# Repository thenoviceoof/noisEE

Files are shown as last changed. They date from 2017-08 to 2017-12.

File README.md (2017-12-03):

noiseEE
================================================================================
Code to find a set of easily derivable software filters to produce
different flavors of noise and intermediate stages, and a hardware
realization.

If you want a full explanation of the project, see notes [part
1](http://thenoviceoof.com/blog/projects/noisee-part-1-software/) and
[part
2](http://thenoviceoof.com/blog/projects/noisee-part-2-hardware/).

**NOTE**: the hardware rendition does not work, and will be expensive
in time to correct. This project is abandoned.

filter/
--------------------------------------------------------------------------------
Contains scripts to help find and visualize the filter parameters.

- `exploration_parameters.py`: exploratory work, lots of commented out
  code. Generates graphics to investigate whether simple linear
  parameter interpolation would work.

- `ideal_parameters.py`: hill climb the gain parameters of a joint
  filter made of 3 low pass filters to create linear slope
  approximations, using ideal filter transfer functions. Generates
  `gains.csv`.

- `linear_approximation.R`: takes in `gains.csv` (currently a more
  specific name; you'll need to edit the file) and uses R's segmented
  library to get a piecewise linear approximation. Generates
  `linear_parameters.csv`.

- `generate_hardware_parameter.py`: takes in `linear_parameters.csv`,
  and prints out 16-bit fixed-point integer gain parameters for use in
  `noisEE.c`.

There are also scripts generating multimedia:

- `generate_audio.py`: given the piecemeal results in
  `linear_parameters.csv`, generate a WAV file sweeping from white to
  red noise.

- `visualized_spectrum.py`: running this will generate figures used in
  [part 1 of the project
  notes](http://thenoviceoof.com/blog/projects/noisee-part-1-software/).

- `visualized_animated_spectrum.py`: running this will generate
  animation frames used for the spectrum animation in [part 1 of the
  project
  notes](http://thenoviceoof.com/blog/projects/noisee-part-1-software/).

hardware/
--------------------------------------------------------------------------------
Contains the hardware design files.

- `noisEE-project*`: KiCad design files. Start with the `.pro` project file.

- `noisEE-components*`: contains the OPA227 symbol and MEE1SC footprint
  for KiCad.

- `case__1_5mm.svg/case__3_0mm.svg`: the SVG design files fit into
  Ponoko's P1 template, meant for their respective wood thicknesses.

- `case_*.svg`: these SVGs are intermediate design files, mostly
  correcting for laser kerf.

avr/
--------------------------------------------------------------------------------
Contains files for programming the AVR.

- `Makefile`: just run `make` to build and upload, if you have `avr-gcc`
  and `avrdude` on your path, and are using the ISP MKII. You'll need
  to edit this file if you're using something else.

- `noisEE.c`: currently in a bad state, checkpointed in the middle of
  testing how each filter affects the final response. If you want to
  continue work, you'll need to remove the test loop and uncomment the
  real runtime loop.

(other)
--------------------------------------------------------------------------------

- `test_binary_search_loop.py`: a quick script to make sure that a
  binary search on the calculated filter values will terminate.

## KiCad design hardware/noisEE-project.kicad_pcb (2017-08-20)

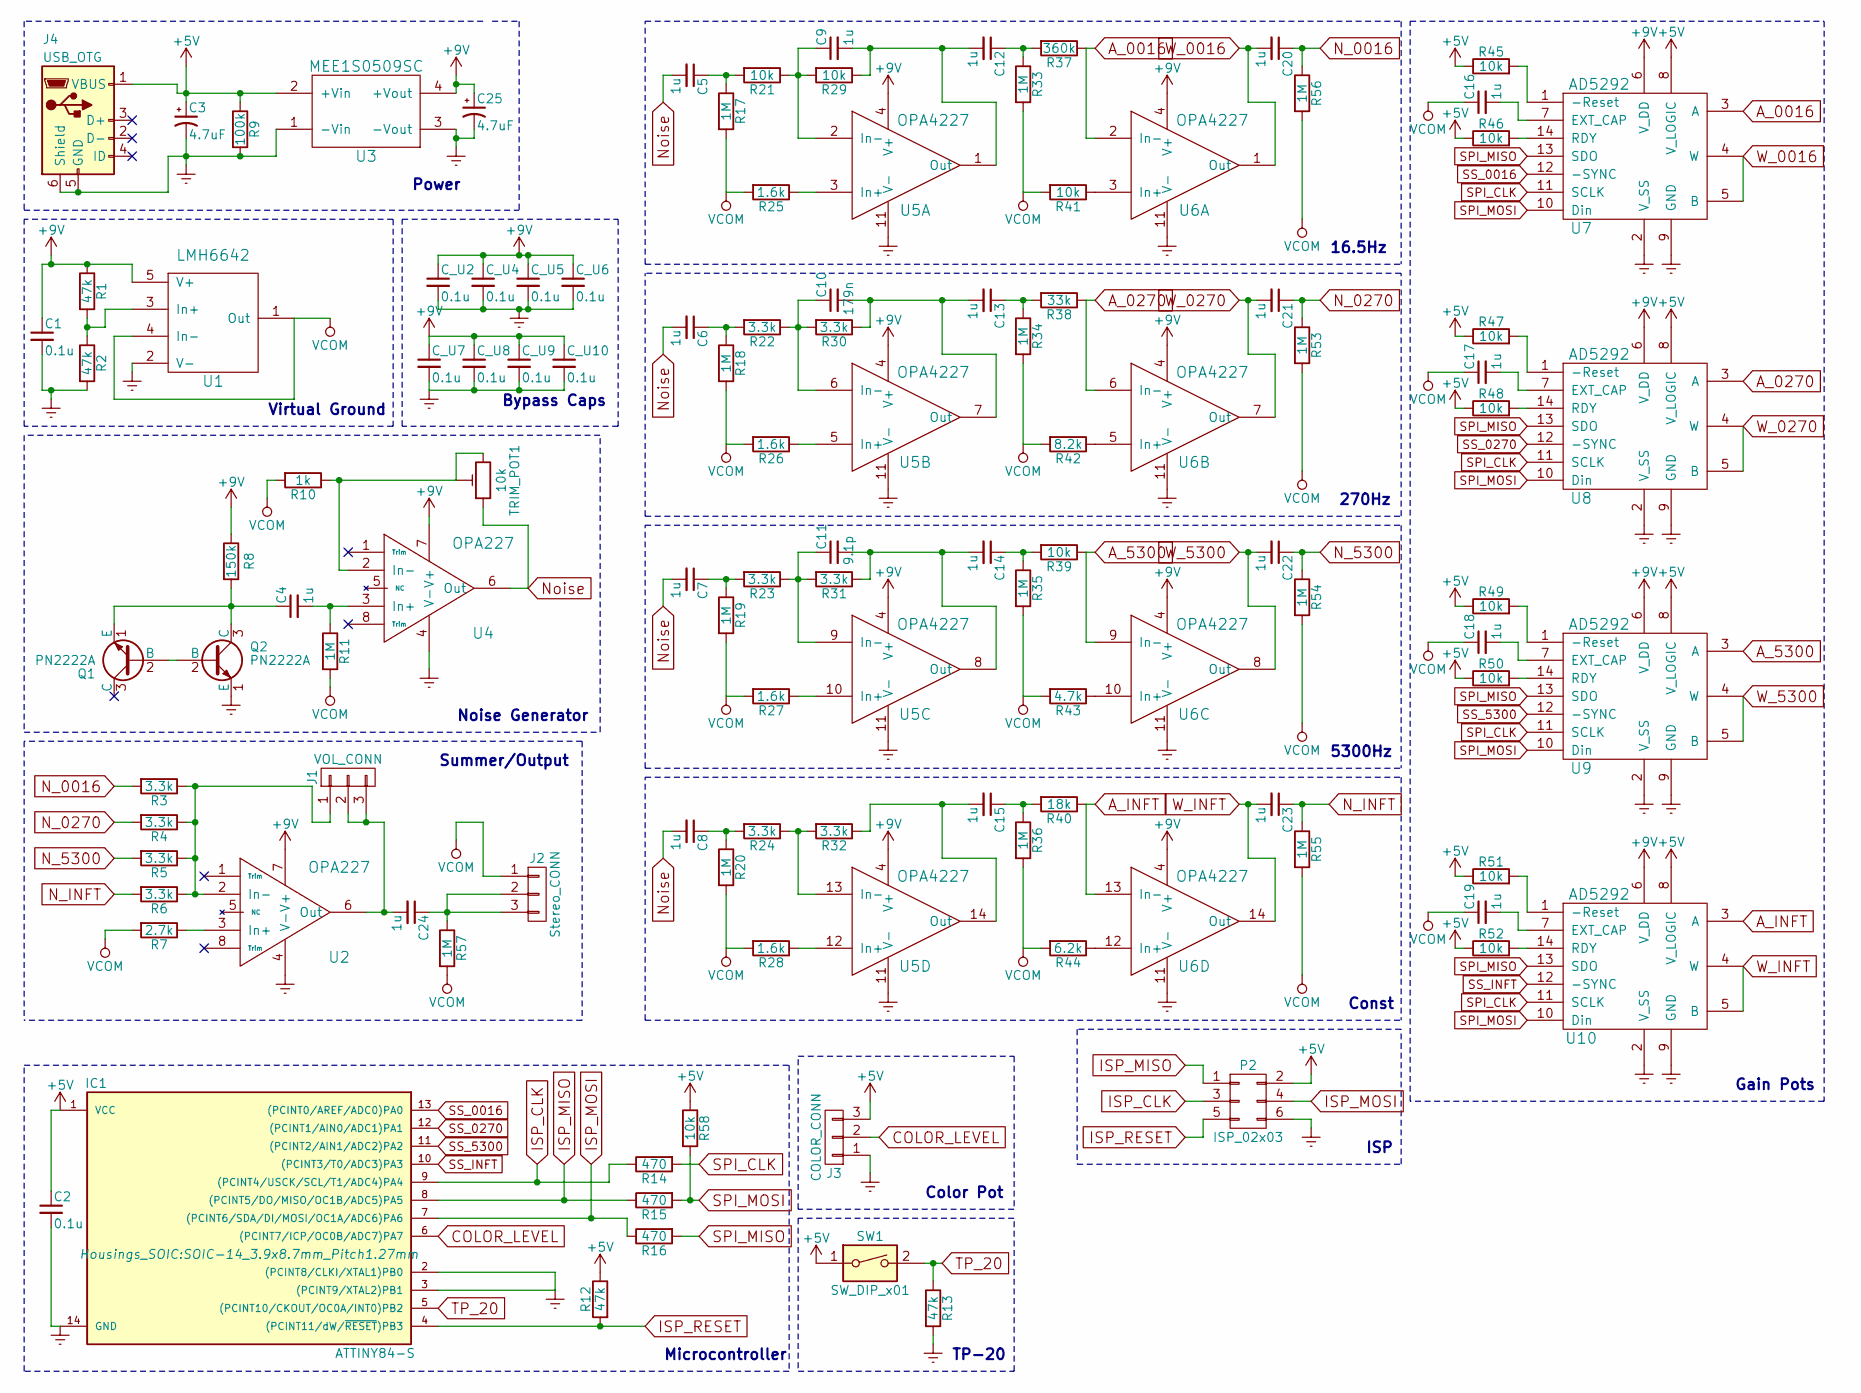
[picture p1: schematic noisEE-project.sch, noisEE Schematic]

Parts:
C1, C2: 0.1u; C_0805
C3, C25: 4.7uF; CP_Radial_D8.0mm_P3.50mm
C4, C5, C6, C7, C8, C9, C12, C13, C14, C15, C16, C17, C18, C19, C20, C21, C22, C23, C24: 1u; C_0805
C10: 179n; C_0805
C11: 9.1p; C_0805
C_U2, C_U4, C_U5, C_U6, C_U7, C_U8, C_U9, C_U10: 0.1u; C_0805
IC1: ATTINY84-S; SOIC-14_3.9x8.7mm_Pitch1.27mm
J1: VOL_CONN; Pin_Header_Straight_1x03_Pitch2.54mm
J2: Stereo_CONN; Pin_Header_Straight_1x03_Pitch2.54mm
J3: COLOR_CONN; Pin_Header_Straight_1x03_Pitch2.54mm
J4: USB_OTG; USB_Micro-B_10103594-0001LF
P2: ISP_02x03; Pin_Header_Straight_2x03_Pitch2.54mm
Q1, Q2: PN2222A; TO-92_Inline_Wide
R1, R2, R12, R13: 47k; R_0805
R3, R4, R5, R6, R22, R23, R24, R30, R31, R32: 3.3k; R_0805
R7: 2.7k; R_0805
R8: 150k; R_0805
R9: 100k; R_0805
R10: 1k; R_0805
R11, R17, R18, R19, R20, R33, R34, R35, R36, R53, R54, R55, R56, R57: 1M; R_0805
R14, R15, R16: 470; R_0805
R21, R29, R39, R41, R45, R46, R47, R48, R49, R50, R51, R52, R58: 10k; R_0805
R25, R26, R27, R28: 1.6k; R_0805
R37: 360k; R_0805
R38: 33k; R_0805
R40: 18k; R_0805
R42: 8.2k; R_0805
R43: 4.7k; R_0805
R44: 6.2k; R_0805
SW1: SW_DIP_x01; SW_TH_Tactile_Omron_B3F-10xx
TRIM_POT1: 10k; Potentiometer_Trimmer_Bourns_3339P_Horizontal
U1: LMH6642; SOT-23-5
U2, U4: OPA227; SOIC-8_3.9x4.9mm_Pitch1.27mm
U3: MEE1S0509SC; MEE1SC
U5, U6: OPA4227; SOIC-14_3.9x8.7mm_Pitch1.27mm
U7, U8, U9, U10: AD5292; TSSOP-14_4.4x5mm_Pitch0.65mm

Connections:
+5V: C2.1, C3.1, IC1.1 (VCC), J3.3, J4.1 (VBUS), P2.2, R9.1, R12.1, R45.1, R46.1, R47.1, R48.1, R49.1, R50.1, R51.1, R52.1, R58.1, SW1.1, U3.2 (+Vin), U7.8 (V_LOGIC), U8.8 (V_LOGIC), U9.8 (V_LOGIC), U10.8 (V_LOGIC)
+9V: C1.1, C25.1, C_U2.1, C_U4.1, C_U5.1, C_U6.1, C_U7.1, C_U8.1, C_U9.1, C_U10.1, R1.1, R8.1, U1.5 (V+), U2.7 (V+), U3.4 (+Vout), U4.7 (V+), U5.4 (V+), U6.4 (V+), U7.6 (V_DD), U8.6 (V_DD), U9.6 (V_DD), U10.6 (V_DD); also elsewhere on the board
A_0016: R37.1, U6.2 (In-), U7.3 (A)
A_0270: R38.1, U6.6 (In-), U8.3 (A)
A_5300: R39.1, U6.9 (In-), U9.3 (A)
A_INFT: R40.1, U6.13 (In-), U10.3 (A)
COLOR_LEVEL: IC1.6 ((PCINT7/ICP/OC0B/ADC7)PA7), J3.2
Earth: C1.2, C2.2, C3.2, C25.2, C_U2.2, C_U4.2, C_U5.2, C_U6.2, C_U7.2, C_U8.2, C_U9.2, C_U10.2, IC1.2 ((PCINT8/CLKI/XTAL1)PB0), IC1.3 ((PCINT9/XTAL2)PB1), IC1.14 (GND), J3.1, J4.5 (GND), J4.6 (Shield), P2.6, Q2.1 (E), R2.2, R9.2, R13.2, U1.2 (V-), U2.4 (V-), U3.1 (-Vin), U3.3 (-Vout), U4.4 (V-), U5.11 (V-), U6.11 (V-), U7.2 (V_SS), U7.9 (GND), U8.2 (V_SS), U8.9 (GND), U9.2 (V_SS), U9.9 (GND), U10.2 (V_SS), U10.9 (GND); also elsewhere on the board
ISP_CLK: IC1.9 ((PCINT4/USCK/SCL/T1/ADC4)PA4), P2.3, R14.1
ISP_MISO: IC1.8 ((PCINT5/DO/MISO/OC1B/ADC5)PA5), P2.1, R15.1
ISP_MOSI: IC1.7 ((PCINT6/SDA/DI/MOSI/OC1A/ADC6)PA6), P2.4, R16.1
ISP_RESET: IC1.4 ((PCINT11/dW/~RESET~)PB3), P2.5, R12.2
N_0016: C20.1, R3.2, R56.1
N_0270: C21.1, R4.2, R53.1
N_5300: C22.1, R5.2, R54.1
N_INFT: C23.1, R6.2, R55.1
unnamed: C4.1, Q1.1 (E), Q2.3 (C), R8.2
unnamed: C4.2, R11.1, U4.3 (In+)
unnamed: C5.1, R17.1, R21.2
unnamed: C6.1, R18.1, R22.2
unnamed: C7.1, R19.1, R23.2
unnamed: C8.1, R20.1, R24.2
unnamed: C9.1, R21.1, R29.2, U5.2 (In-)
unnamed: C10.1, R22.1, R30.2, U5.6 (In-)
unnamed: C10.2, C13.2, R30.1, U5.7 (Out)
unnamed: C11.1, R23.1, R31.2, U5.9 (In-)
unnamed: C11.2, C14.2, R31.1, U5.8 (Out)
unnamed: C12.1, R33.1, R37.2
unnamed: C9.2, C12.2, R29.1, U5.1 (Out)
unnamed: C13.1, R34.1, R38.2
unnamed: C14.1, R35.1, R39.2
unnamed: C15.1, R36.1, R40.2
unnamed: C15.2, R32.1, U5.14 (Out)
unnamed: C16.2, U7.7 (EXT_CAP)
unnamed: C17.2, U8.7 (EXT_CAP)
unnamed: C18.2, U9.7 (EXT_CAP)
unnamed: C19.2, U10.7 (EXT_CAP)
unnamed: C24.1, J2.2, J2.3, R57.1
unnamed: C24.2, J1.2, J1.3, U2.6 (Out)
unnamed: J1.1, R3.1, R4.1, R5.1, R6.1, U2.2 (In-)
unnamed: Q1.2 (B), Q2.2 (B)
unnamed: R1.2, R2.1, U1.3 (In+)
unnamed: R7.1, U2.3 (In+)
unnamed: R10.1, TRIM_POT1.2, TRIM_POT1.3, U4.2 (In-)
unnamed: R24.1, R32.2, U5.13 (In-)
unnamed: R25.1, U5.3 (In+)
unnamed: R26.1, U5.5 (In+)
unnamed: R27.1, U5.10 (In+)
unnamed: R28.1, U5.12 (In+)
unnamed: R41.1, U6.3 (In+)
unnamed: R42.1, U6.5 (In+)
unnamed: R43.1, U6.10 (In+)
unnamed: R44.1, U6.12 (In+)
unnamed: R45.2, U7.1 (-Reset)
unnamed: R46.2, U7.14 (RDY)
unnamed: R47.2, U8.1 (-Reset)
unnamed: R48.2, U8.14 (RDY)
unnamed: R49.2, U9.1 (-Reset)
unnamed: R50.2, U9.14 (RDY)
unnamed: R51.2, U10.1 (-Reset)
unnamed: R52.2, U10.14 (RDY)
Noise: C5.2, C6.2, C7.2, C8.2, TRIM_POT1.1, U4.6 (Out)
SPI_CLK: R14.2, U7.11 (SCLK), U8.11 (SCLK), U9.11 (SCLK), U10.11 (SCLK)
SPI_MISO: R16.2, U7.13 (SDO), U8.13 (SDO), U9.13 (SDO), U10.13 (SDO)
SPI_MOSI: R15.2, R58.2, U7.10 (Din), U8.10 (Din), U9.10 (Din), U10.10 (Din)
SS_0016: IC1.13 ((PCINT0/AREF/ADC0)PA0), U7.12 (-SYNC)
SS_0270: IC1.12 ((PCINT1/AIN0/ADC1)PA1), U8.12 (-SYNC)
SS_5300: IC1.11 ((PCINT2/AIN1/ADC2)PA2), U9.12 (-SYNC)
SS_INFT: IC1.10 ((PCINT3/T0/ADC3)PA3), U10.12 (-SYNC)
TP_20: IC1.5 ((PCINT10/CKOUT/OC0A/INT0)PB2), R13.1, SW1.2
VCOM: C16.1, C17.1, C18.1, C19.1, J2.1, R7.2, R10.2, R11.2, R17.2, R18.2, R19.2, R20.2, R25.2, R26.2, R27.2, R28.2, R33.2, R34.2, R35.2, R36.2, R41.2, R42.2, R43.2, R44.2, R53.2, R54.2, R55.2, R56.2, R57.2, U1.1 (Out), U1.4 (In-)
W_0016: C20.2, U6.1 (Out), U7.4 (W), U7.5 (B)
W_0270: C21.2, U6.7 (Out), U8.4 (W), U8.5 (B)
W_5300: C22.2, U6.8 (Out), U9.4 (W), U9.5 (B)
W_INFT: C23.2, U6.14 (Out), U10.4 (W), U10.5 (B)

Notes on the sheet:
Power
Noise Generator
Summer/Output
Virtual Ground
16.5Hz
270Hz
5300Hz
Const
ISP
TP-20
Color Pot
Microcontroller
Gain Pots
Bypass Caps

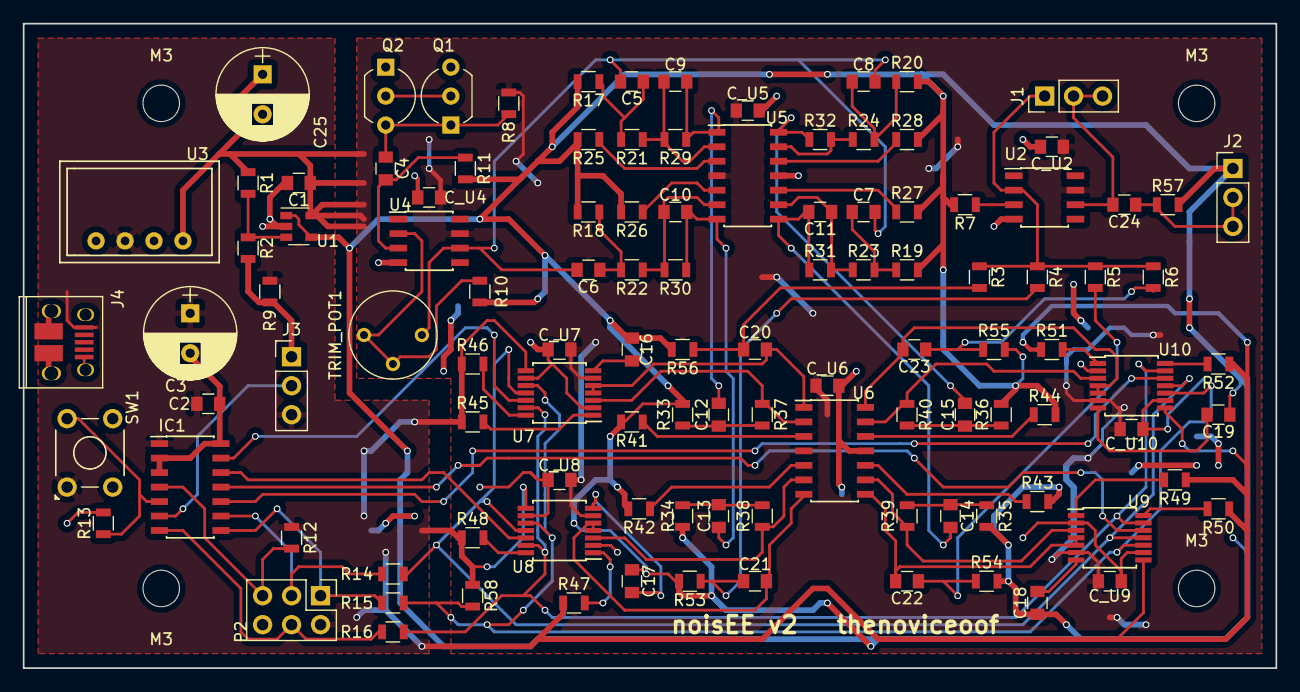
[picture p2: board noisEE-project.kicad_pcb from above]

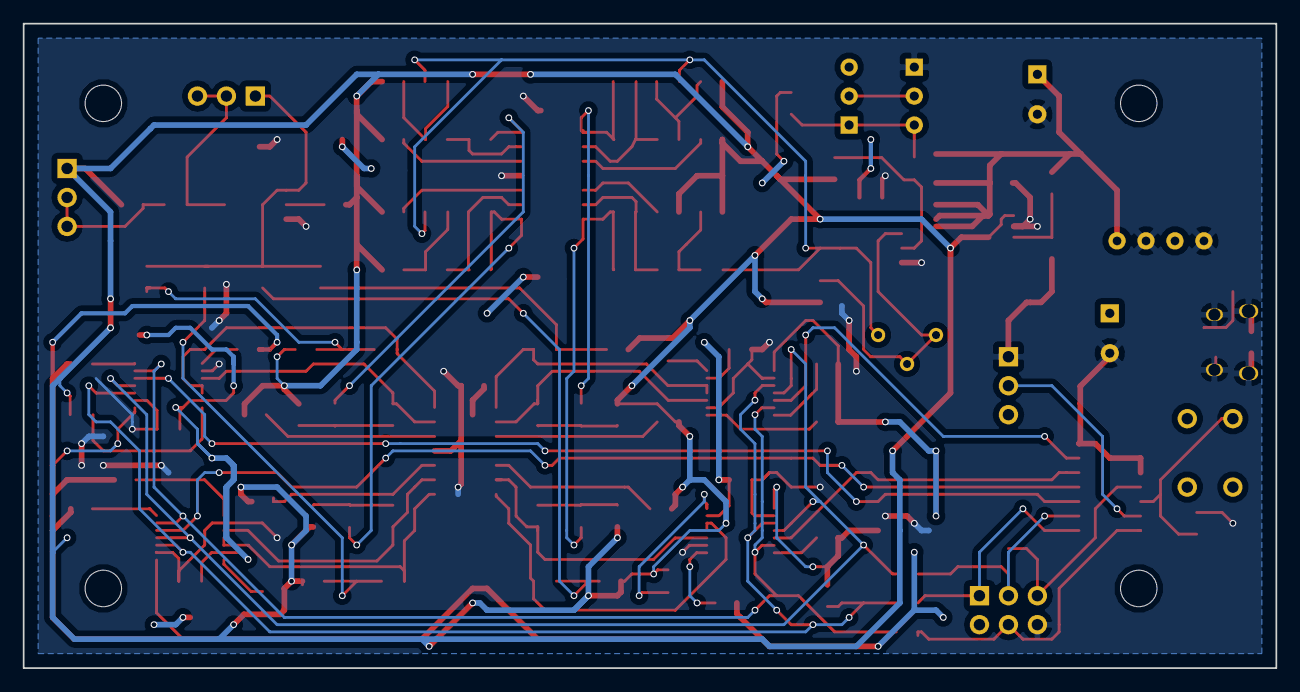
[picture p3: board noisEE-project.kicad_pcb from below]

Board: 2 copper layers, 109.9 x 56.5 mm, 123 parts (2 on the bottom side), 75 nets.

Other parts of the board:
A: plane_pad
B: plane_pad
C: plane_pad
D: plane_pad
M3, M3#2, M3#3, M3#4: MountingHole_3.2mm_M3
X: plane_pad
Y: plane_pad
Z: plane_pad
e: plane_pad

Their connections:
+9V: D.1, X.1, e.1; also elsewhere on the board
Earth: A.1, B.1, C.1, Y.1, Z.1; also elsewhere on the board

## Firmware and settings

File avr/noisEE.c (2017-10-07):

// Copyright 2017 "Nathan Hwang" <thenoviceoof>
//
// Licensed under the Apache License, Version 2.0 (the "License");
// you may not use this file except in compliance with the License.
// You may obtain a copy of the License at
//
//     http://www.apache.org/licenses/LICENSE-2.0
//
// Unless required by applicable law or agreed to in writing, software
// distributed under the License is distributed on an "AS IS" BASIS,
// WITHOUT WARRANTIES OR CONDITIONS OF ANY KIND, either express or implied.
// See the License for the specific language governing permissions and
// limitations under the License.

#include <avr/cpufunc.h>  // Provides _NOP
#include <avr/interrupt.h>
#include <avr/io.h>
#include <avr/sleep.h>

// Forward declares.

uint16_t interpolatePiecewiseLinearFunction(uint16_t unpaddedX,
                                            uint16_t xs[8], uint16_t ys[8]);

void writeDisableWriteProtect();

void writeFilterValue(int value);

void writeSPIValue(char byte);

/**
 * Fix point constants for mapping the color value to the various
 * filter parameters.
 *
 * The numbers represent a piecewise linear approximation to the
 * parameter functions. The maximum "Y" value caps out at 2**15; the
 * hardware component values are chosen to get the right scale. There
 * are only 2**10 possible pot values, but snapping these
 * approximation values to the nearest 10 bit value would give up some
 * accuracy in the interpolation.
 *
 * The domain is scaled to fill 2**15: there are only 2**10 ADC
 * values, but we want more accuracy, similar to the range argument
 * given above.
 *
 * The interpolation calculation uses 32 bit ints, treating the 15 bit
 * filter parameter and 10 bit input as fixed point numbers.
 *
 * We use 2 bytes because 1 byte only covers 8 bits, and we have 10
 * bits of input and output. This way, we do not drop accuracy
 * needlessly.
 */
uint16_t filter0016x[8] = {0, 5734, 11693, 16030, 19274, 21684, 29121, 32767};
uint16_t filter0016y[8] = {0, 1478, 6579, 13111, 22962, 26764, 29850, 32767};

uint16_t filter0270x[8] = {0, 3400, 9726, 16331, 19395, 22078, 25416, 32767};
uint16_t filter0270y[8] = {1612, 6132, 22206, 32767, 13003, 4342, 807, 0};

uint16_t filter5300x[8] = {0, 2219, 7419, 10704, 16275, 20965, 24791, 32767};
uint16_t filter5300y[8] = {5264, 10757, 28662, 32767, 29869, 8733, 1838, 0};

// Plain white noise source filter parameters.
uint16_t filter0000x[8] = {0, 3468, 9517, 11880, 15385, 25149, 28630, 32767};
uint16_t filter0000y[8] = {32767, 32249, 10444, 5091, 1519, 363, 180, 80};

void calculateFilterParameters(uint16_t input, uint16_t *filter0016,
                               uint16_t *filter0270, uint16_t *filter5300,
                               uint16_t *filter0000) {
        // Cap the input at legal values for 10 bits of input, since
        // the ADC maxes out at 10 bits.
        if(input < 0) {
                input = 0;
        }
        if(input > 1023) {
                input = 1023;
        }

        // For each filter, interpolate the real value from the filter
        // definition arrays.
        *filter0016 = interpolatePiecewiseLinearFunction(
                input, filter0016x, filter0016y);
        *filter0270 = interpolatePiecewiseLinearFunction(
                input, filter0270x, filter0270y);
        *filter5300 = interpolatePiecewiseLinearFunction(
                input, filter5300x, filter5300y);
        *filter0000 = interpolatePiecewiseLinearFunction(
                input, filter0000x, filter0000y);

        // Cap the values at both ends.
        if(*filter0016 > 1023) {
                *filter0016 = 1023;
        }
        if(*filter0016 < 0) {
                *filter0016 = 0;
        }
        if(*filter0270 > 1023) {
                *filter0270 = 1023;
        }
        if(*filter0270 < 0) {
                *filter0270 = 0;
        }
        if(*filter5300 > 1023) {
                *filter5300 = 1023;
        }
        if(*filter5300 < 0) {
                *filter5300 = 0;
        }
        if(*filter0000 > 1023) {
                *filter0000 = 1023;
        }
        if(*filter0000 < 0) {
                *filter0000 = 0;
        }
}

uint16_t interpolatePiecewiseLinearFunction(uint16_t unpaddedX,
                                            uint16_t xs[8], uint16_t ys[8]) {
        // x is a 10-bit value, make it comparable to the 15-bit domain values.
        uint16_t x = (unpaddedX << 5);
        
        // Binary search through the xs array to find the two values
        // we should be interpolating between.
        // The current index represents the range that we expect the
        // value to be within.
        char minIndex = 0;
        char maxIndex = 6; // The max index is 7, but it's just an endpoint.
        while(minIndex != maxIndex) {
                char midIndex = (minIndex + maxIndex)/2;
                if(x < xs[midIndex]) {
                        maxIndex = midIndex - 1;
                } else if(x > xs[midIndex + 1]) {
                        minIndex = midIndex + 1;
                } else {
                        maxIndex = midIndex;
                        break;
                }
        }

        // Now, maxIndex is the index of the lower endpoint of the
        // segment containing the value.
        // Since we're subtracting from the lower endpoint, our value
        // will always be positive.
        uint16_t t = x - xs[maxIndex];
        // Interpolate within the range of values.
        // Using a 16 bit signed value is fine, since we're dealing
        // with 15 bit values.
        int16_t dx = xs[maxIndex + 1] - xs[maxIndex];
        int16_t dy = ys[maxIndex + 1] - ys[maxIndex];
        // Theoretically possible for the intermediate value to take
        // up 15 + 15 = 30 bits, so use a signed 32 bit int.
        // The final delta should again fit into 15 bits.
        int16_t delta = ((int32_t) (dy * t)) / dx;
        // Reduce back to 10 bits.
        return (ys[maxIndex] + delta) >> 5;
}

/**
 * The previous output value of the individual filter parameters.
 */
uint16_t PREVIOUS_FILTER_0016 = 0;
uint16_t PREVIOUS_FILTER_0270 = 0;
uint16_t PREVIOUS_FILTER_5300 = 0;
uint16_t PREVIOUS_FILTER_0000 = 0;

void unselect() {
        // Unselect the device, wait for RDY in max 2.4uS (default R-Perf mode).
        PORTA |= (1 << PCINT0) | (1 << PCINT1) | (1 << PCINT2) | (1 << PCINT3);
        _NOP();
        _NOP();
        _NOP();
}

void selectWait() {
        // Wait 2 ns for RDY after chip select (SS).
        _NOP();
}

void calculateAndWriteFilterValues(int input) {
        uint16_t filter0016 = 0;
        uint16_t filter0270 = 0;
        uint16_t filter5300 = 0;
        uint16_t filter0000 = 0;
        calculateFilterParameters(
                input,
                &filter0016,
                &filter0270,
                &filter5300,
                &filter0000
                );

        // For each device, select and then write the value over SPI.
        // Note that the active pin is LOW, not HIGH.
        // TEST TEST TEST: ALWAYS WRITE EACH VALUE
        /* if (filter0016 != PREVIOUS_FILTER_0016) { */
        if (1) {
                PREVIOUS_FILTER_0016 = filter0016;
                PORTA = (PORTA & ~(1 << PCINT0)) |
                        (1 << PCINT1) | (1 << PCINT2) | (1 << PCINT3);
                selectWait();
                writeFilterValue(filter0016);
                unselect();
        }
        /* if (filter0270 != PREVIOUS_FILTER_0270) { */
        if (1) {
                PREVIOUS_FILTER_0270 = filter0270;
                PORTA = (PORTA & ~(1 << PCINT1)) |
                        (1 << PCINT0) | (1 << PCINT2) | (1 << PCINT3);
                selectWait();
                writeFilterValue(filter0270);
                unselect();
        }
        /* if (filter5300 != PREVIOUS_FILTER_5300) { */
        if (1) {
                PREVIOUS_FILTER_5300 = filter5300;
                PORTA = (PORTA & ~(1 << PCINT2)) |
                        (1 << PCINT0) | (1 << PCINT1) | (1 << PCINT3);
                selectWait();
                writeFilterValue(filter5300);
                unselect();
        }
        /* if (filter0000 != PREVIOUS_FILTER_0000) { */
        if (1) {
                PREVIOUS_FILTER_0000 = filter0000;
                PORTA = (PORTA & ~(1 << PCINT3)) |
                        (1 << PCINT0) | (1 << PCINT1) | (1 << PCINT2);
                selectWait();
                writeFilterValue(filter0000);
                unselect();
        }
}

void enableAllDevices() {
        // Make sure all devices are not selected.
        unselect();

        // Start with a low USCK/SCL
        PORTA &= ~(1 << PCINT4);

        // For each device, select and then write the value over SPI.
        // Note that the active pin is LOW, not HIGH.
        // Pin 13.
        PORTA = (PORTA & ~(1 << PCINT0)) |
                (1 << PCINT1) | (1 << PCINT2) | (1 << PCINT3);
        selectWait();
        writeDisableWriteProtect();
        unselect();
        
        // Pin 12.
        PORTA = (PORTA & ~(1 << PCINT1)) |
                (1 << PCINT0) | (1 << PCINT2) | (1 << PCINT3);
        selectWait();
        writeDisableWriteProtect();
        unselect();

        // Pin 11.
        PORTA = (PORTA & ~(1 << PCINT2)) |
                (1 << PCINT0) | (1 << PCINT1) | (1 << PCINT3);
        selectWait();
        writeDisableWriteProtect();
        unselect();

        // Pin 10.
        PORTA = (PORTA & ~(1 << PCINT3)) |
                (1 << PCINT0) | (1 << PCINT1) | (1 << PCINT2);
        selectWait();
        writeDisableWriteProtect();
        unselect();
}

/**
 * Disable write protection on the potentiometers.
 */
void writeDisableWriteProtect() {
        // Write 1 => C1 (write protection bit).
        // Command: 00|0110|00 - 0000|00(C1)0
        //  C0 - 20-TP program enable.
        //  C1 - write protection.
        //  C2 - calibration enable.
        //  C3 - TP-20 program success.
        // so, everything else should be 0.
        writeSPIValue((1 << 4) | (1 << 3));
        writeSPIValue((1 << 1));
}

void writeFilterValue(int value) {
        // A wiper value of 0 corresponds to the full resistance, and
        // hence the maximum loudness. Invert the value to have
        // familiar bigger-louder semantics.
        value = 1023 - value;

        // Write command: 00|0001|DD - Dx8
        // Send the first byte, a write command and top two data bits.
        writeSPIValue((1 << 2) | (value >> 8));

        // Send the second byte, simply the last 8 data bits.
        writeSPIValue(value & 255);
}

void writeSPIValue(char byte) {
        // Load up the byte to write.
        USIDR = byte;
        // Clear the counter/counter flag.
        USISR |= (1 << USIOIF);

        // If we're not done shifting yet, keep shifting.
        while(!(USISR & (1 << USIOIF))) {
                // Move a bit out.
                USICR |= (1 << USITC);
        }
}

/**
 * Sleep after writing to the potentiometers.
 */
void sleepForABit() {
        // Use the 8 bit timer.
        // Initialize the timer register.
        TCNT0 = 0;
        
        // Disconnect the timer output pins and use CTC mode.
        TCCR0A |= (1 << WGM01);
        
        // Compare the timer value against the largest 8-bit value.
        OCR0A = 255;
        
        // Trigger an alert when we match OCR0A.
        TIMSK0 |= (1 << OCIE0A);
        
        // With a 64x prescale, 255*64 is 16ms/64Hz maximum update.
        // This also starts the timer.
        TCCR0B |= (1 << CS01) | (1 << CS00);
                                
        // Keep peripherals (like the timer) running while sleeping.
        set_sleep_mode(SLEEP_MODE_IDLE);
        // Enable interrupts.
        sei();
        // Sleep until the timer triggers.
        sleep_mode();
}

/**
 * Handle TP-20 writes requests to the digital potentiometer (AD5292).
 *
 * TP-20 is the on-boot memory of the digital potentiometers: letting
 * all the potentiometers start at the middle of their ranges probably
 * produces weird results. Instead, we can write a value to
 * non-volatile memory that the potentiometer will remember while
 * powered down, and boot with that value. This burn is only possible
 * 20 times, which is why it's called TP-20.
 */

void handleTP20Request() {
        // TODO: implement TP20 functionality if necessary.
}

// Global TP-20 request bit.
char GlobalTP20Setting = 0;

// Out of an abundance of caution, only write once per power cycle. It
// sure would be a shame if I burned all 20 writes in less than a
// second due to a mistake in wiring/coding.
char wroteTP20 = 0;

/**
 * Global state machine
 */
typedef enum {
        SleepingState = 0,
        WaitingForReadState,
        WriteValueState
} State;

State GlobalState;
uint16_t ADCValue = 0;
uint16_t PreviousADCValue = 0;

void main() {
        /* -- Initial Configuration ----------------------------------------- */
        // By default, the internal 8MHz oscillator is used, and the
        // clock prescaler runs at 1/8 f_clk.
        
        // Set up the ADC for the color pin.
        // With 1Mhz default internal clock, 32x prescale gives the ADC a 30kHz
        // clock (50-200kHz needed for 10 bit resolution).
        // By default, the ADC7 pin is configured as input.
        ADCSRA |=
                (1 << ADEN) | // Enable the ADC.
                // (1 << ADIE) | // Enable ADC complete interrupts.
                (1 << ADPS2) | (1 << ADPS0); // Set the ADC prescaler to 32x.
        ADMUX |=
                // Use Vcc as the reference.
                (0 << REFS0) | (0 << REFS1) |
                // Select ADC7 (PCINT7).
                (1 << MUX2) | (1 << MUX1) | (1 << MUX0);
        
        // Set up the SPI communications channels.
        DDRA |=
                // Set the direction for the chip select pins
                // (PA0/PA1/PA2/PA3 for 16,270,5300,inft
                // respectively).
                (1 << PCINT0) | (1 << PCINT1) | (1 << PCINT2) | (1 << PCINT3)
                // Set the direction for the SPI pins SCL and MOSI
                // (MISO is default input).
                // NOTE: ATTiny84 marks MOSI/MISO, but this is the
                //   opposite of what we expect. In the context of
                //   programming the ATTiny, the master is the
                //   programming device. Hence, you should look at the
                //   DO/DI designation instead.
                | (1 << PCINT4 /* USCK/SCL */)
                | (1 << PCINT5 /* DO/real MOSI */);

        // Configure the SPI device.
        USICR |=
                (0 << USIWM1) | (1 << USIWM0) // Use 3-wire (SPI) mode.
                // Don't use the USIOIE (overflow interrupt) in favor of
                // software strobe.
                // Use software clock strobe (USITC), Mode 1 (falling edge).
                | (1 << USICS1) | (1 << USICS0) | (1 << USICLK)
                ;

        uint16_t i = 0;
        // Wait for the pots to set up: 2ms max power-on OTP restore time.
        for(i = 0; i < 800; i++) {
                _NOP();
        }
        
        // Configure each pot to not be read-only.
        enableAllDevices();

        /* -- Main Loop ----------------------------------------------------- */
        // THIS IS A TEST LOOP.
        uint16_t j = 0;
        uint16_t k = 0;
        while (1) {
                for (k = 0; k < 6543; k++) {
                        _NOP();
                }
                /* j += 1; */
                /* j %= 1024; */
                /* calculateAndWriteFilterValues(j); */

                PORTA = (PORTA & ~(1 << PCINT0)) |
                        (1 << PCINT1) | (1 << PCINT2) | (1 << PCINT3);
                selectWait();
                writeFilterValue(1023);
                unselect();

                PORTA = (PORTA & ~(1 << PCINT1)) |
                        (1 << PCINT0) | (1 << PCINT2) | (1 << PCINT3);
                selectWait();
                writeFilterValue(1023);
                unselect();

                PORTA = (PORTA & ~(1 << PCINT2)) |
                        (1 << PCINT0) | (1 << PCINT1) | (1 << PCINT3);
                selectWait();
                writeFilterValue(1023);
                unselect();

                PORTA = (PORTA & ~(1 << PCINT3)) |
                        (1 << PCINT0) | (1 << PCINT1) | (1 << PCINT2);
                selectWait();
                writeFilterValue(1023);
                unselect();
        }

        // THIS IS THE REAL LOOP.
        /* while(1) { */
        /*         if(GlobalTP20Setting && wroteTP20 == 0) { */
        /*                 handleTP20Request(); */
        /*                 GlobalTP20Setting = 0; */
        /*                 wroteTP20 = 1; */
        /*         } else { */
        /*                 switch(GlobalState) { */
        /*                 case SleepingState: */
        /*                         GlobalState = WaitingForReadState; */

        /*                         // Sleep until the ADC value is ready. */
        /*                         // Keep peripherals running. */
        /*                         set_sleep_mode(SLEEP_MODE_IDLE); */

        /*                         // Enable interrupts. */
        /*                         sei(); */
        /*                         // Start a read from the ADC. */
        /*                         ADCSRA |= (1 << ADSC) | (1 << ADIE); */
                                
        /*                         // Sleep until the ADC is done. */
        /*                         sleep_mode(); */
        /*                         // while () ; */
        /*                         break; */
        /*                 case WriteValueState: */
        /*                         // Read from the ADC, and write to the */
        /*                         // potentiometers. */
        /*                         ADCValue = ADC; */
        /*                         if(PreviousADCValue < ADCValue - 2 || */
        /*                            PreviousADCValue > ADCValue + 2) { */
        /*                                 calculateAndWriteFilterValues(ADCValue); */
        /*                         } */
        /*                         PreviousADCValue = ADCValue; */
                                
        /*                         // Go to sleep for a while. */
        /*                         GlobalState = SleepingState; */
        /*                         sleepForABit(); */
        /*                         break; */
        /*                 } */
        /*         } */
        /* } */
}

// Handle the ADC conversion finishing.
ISR(ADC_vect) {
        GlobalState = WriteValueState;
        // Disable the ADC interrupts until we need it next time.
        ADCSRA &= ~(1 << ADIE);
}

// Handle the timer triggering.
ISR(TIM0_COMPA_vect) {
        // Wipe the prescale settings to stop the timer.
        TCCR0B &= ~((1 << CS02) | (1 << CS01) | (1 << CS00));
}

/**
 * Register an interrupt for the button press.
 *
 * This does not do the TP-20 set: instead, this just sets a bit, and
 * when the main loop is finished with its work, it will handle the
 * TP-20 communications necessary to burn in the current values.
 */

/*
// TODO
ISR()
void burnPotentiometers() {
        globalTP20Setting = 1;
}
*/

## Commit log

2015-01-02 Use a SAMPLE_RATE constant instead of a bare 44.1k
2015-01-04 Add a cli switch for changing the FFT bucket size
2015-01-04 Average multiple buckets of samples for better spectral accuracy
2015-01-05 Check if the FFT size is a power of 2
2015-01-07 Add a way to apply filters
2015-01-07 Move the slope/filter application into a function
2015-01-07 Add target slope for pinking filter
2015-01-12 Use the error combination algo as the input to the jitter algo
2015-01-12 Tweak the jitter function to not immediately crash
2015-01-12 Add some verbose switch debug print statements
2015-01-14 Update verbose print statements
2015-01-14 Catch floating point overflow errors (caused by bad filters)
2015-01-14 Print calculated combined error in verbose statements
2015-01-15 Clear the updating jitter lines before printing to them
2015-01-16 Pass verbose through, instead of treating as stuck switch
2015-01-16 Add a simple filter definitions for white noise
2015-01-18 Add levels of verbosity (clean up the jitter replacement output when piping to file)
2015-01-19 Force debug output to print, if stdout is being redirected
2015-01-19 Implement a pressure system to get out of local minima
2015-01-19 Fix the verbose print checks
2015-01-20 Add a --filter-size cli arg to allow changing the number of filters
2015-01-20 Use local max pressure as a forcer for multiple parameter changes
2015-02-02 Play with figuring out how to derive the knee from the filter params
2015-02-08 Add a script to explore the passband behavior of various filter params
2015-02-08 More (flipping axis/printing) flags for everyone!
2015-02-16 Get log slope from data + switch
2015-02-18 add tool to see what filters do what (idealized)
2015-03-12 Create a script to compare actual/ideal filters, explore smoothing behavior
2015-04-05 Tweaks to filter_compare display/ideal filter fn
2015-04-05 Add a fixed-point digital filter applier
2015-04-05 Add digital filter to the filter comparisons
2015-04-12 Get input/output bit filters (and internal state filters) actually working
2015-04-15 Add pressure mechanism for loop termination/jitter width
2015-04-29 Add multiprocessing support for analog filter search
2015-04-29 Fix bug in analog filter search, loading previous data
2015-04-29 Fix pressure mechanism (accidentally inverted), up pressure amount
2015-04-29 Use a faster growing pressure mechanism (used to top out at 1db variance)
2015-05-11 Use a looser definition of pressure
2015-05-11 Since we're using a looser definition of pressure, use that for exit conditions
2015-05-12 Allow tweaking parameters from the CLI (+ simplify pressure iterations)
2017-03-11 Hardware checkpoint: schematic done, PCB fits, traces need layout
    [noisEE-project.kicad_pcb, noisEE-project.sch]
2017-03-11 Use two opamps for pre-amp and output stages, clean up board and lay down tracks for all signal paths
    [noisEE-project.kicad_pcb, noisEE-project.sch]
2017-03-11 Laid down almost all tracks. GND and Earth seem to be treated as synonyms
    [noisEE-project.kicad_pcb]
2017-03-12 Split up the ground (GND->VCOM)
    [noisEE-project.kicad_pcb, noisEE-project.sch]
2017-03-12 Get the plane stiches to stay in with hacky net bindings
    [noisEE-project.kicad_pcb]
2017-03-12 Various tweaks: expanding some pours, moved the USB side mounting holes
    [noisEE-project.kicad_pcb]
2017-03-13 Finish a piled-on design for the case
2017-03-13 Try and compensate for kerf in cut designations
2017-03-13 Separate 3mm and 1.5mm board cuts
2017-03-15 Correct for 3.2mm thick sides, not 3mm
2017-03-15 Import current designs into inkscape templates
2017-08-20 Check in v2 hardware with fixes for USI and AD5292 Vss issues
    [noisEE-project.kicad_pcb, noisEE-project.sch]
2017-08-20 Isolate the top plate changes for v2 (mostly wider)
2017-08-20 Remove bak files, and filter them out with .gitignore
2017-08-27 Check in the current AVR code, warts and testing code and all
2017-09-01 Switch the generate_audio script to doing a per-sample filter change
2017-10-07 Generate a series of spectral filter outputs for an animation
2017-10-07 Update KiCad project files for library rescue
2017-10-07 Move filter python scripts into a filter/ directory
